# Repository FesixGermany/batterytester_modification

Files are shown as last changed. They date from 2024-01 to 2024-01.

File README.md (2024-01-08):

# batterytester_modification  

Own design to replace the PCB and the support material of a commercially available battery tester.  
The main PCB is made from 1.5mm FR4 material, the support underneath is 2mm FR4.  
The fixed probe PCB was desoldered and reused, the sliding probe assembly was also reused.  
All tested with 30A current, no excessive heat detected with thermal camera.  
  
Changes made compared to original tester:  
- Slots for sliding probe elongated to accept at least a 18650 comfortably and also button cells  
- Wider traces for higher testing current  
- Longer cables for sliding probe  
- Four big holes added to accept 4mm plugs  
  
KiCAD 3D render of PCB:  
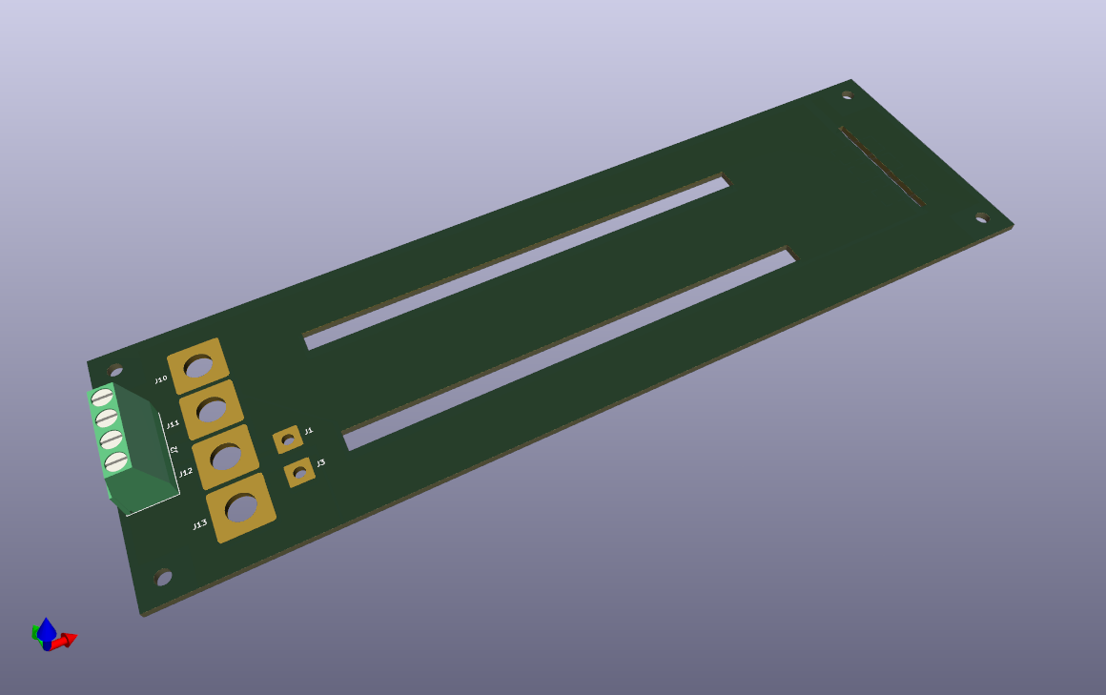
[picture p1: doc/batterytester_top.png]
PCB top
  
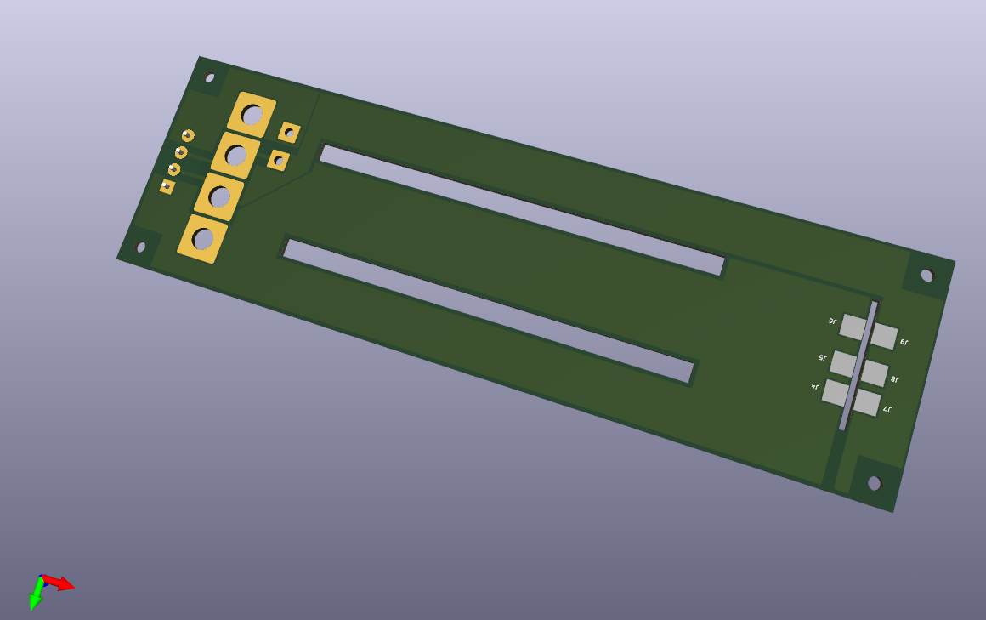
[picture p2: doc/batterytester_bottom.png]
PCB bottom
  
  
Original tester:  
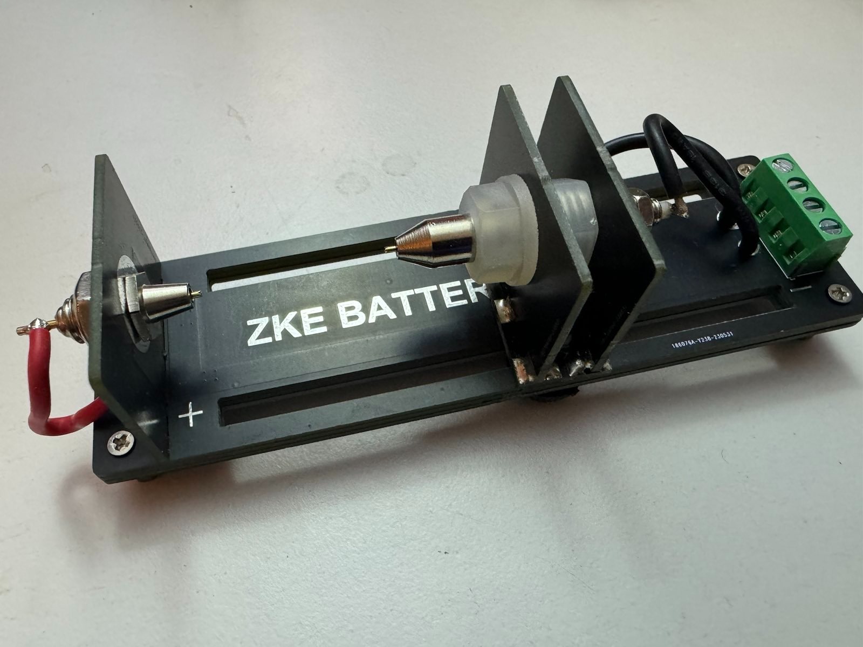
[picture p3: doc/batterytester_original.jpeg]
Original batterytester
  
  
Own version with reused parts:  
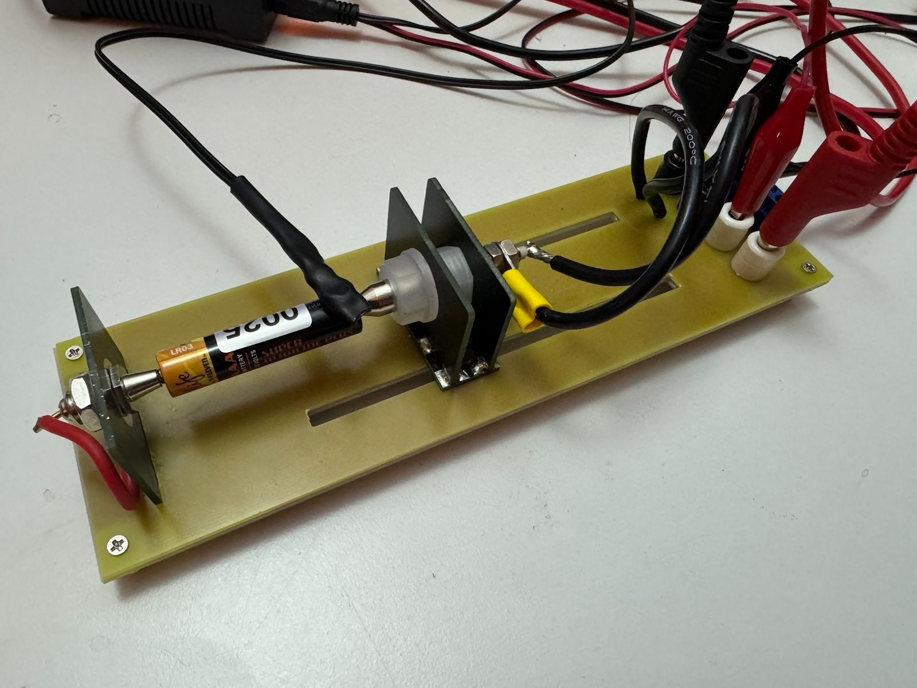
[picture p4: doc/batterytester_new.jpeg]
Tester after modification


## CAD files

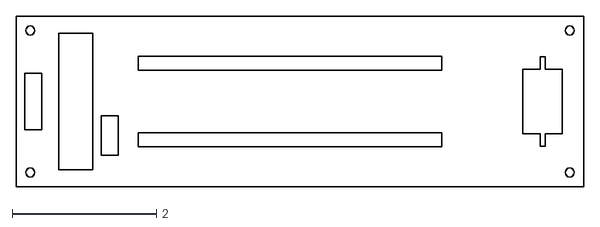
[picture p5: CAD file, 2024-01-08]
gerber_support/batterytester-User_Drawings.dxf
7.87 x 2.36

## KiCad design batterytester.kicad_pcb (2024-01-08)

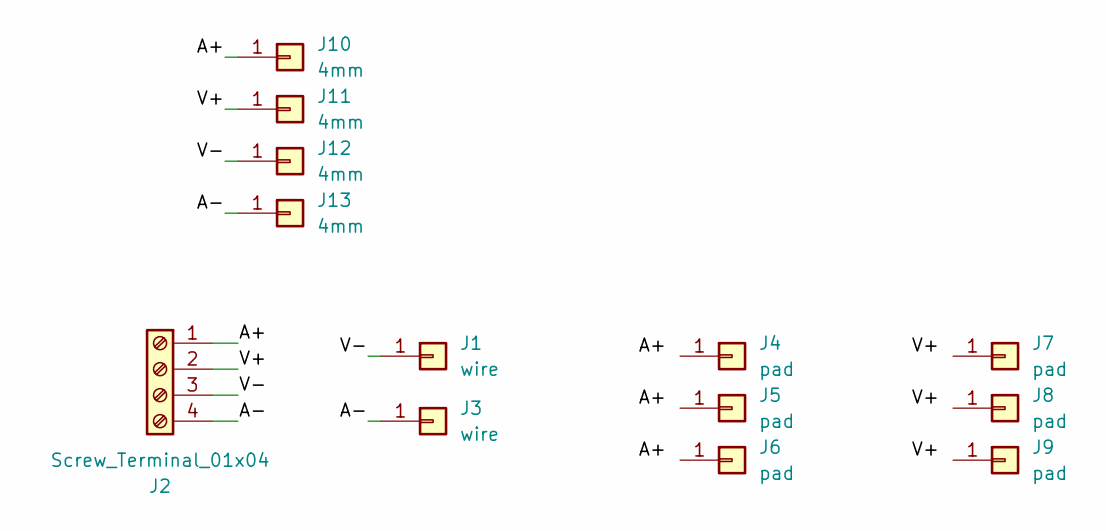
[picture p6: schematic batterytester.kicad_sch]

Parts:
J1, J3: wire; SolderWire-2.5sqmm_1x01_D2.4mm_OD3.6mm
J2: Screw_Terminal_01x04; TerminalBlock_Phoenix_MKDS-1,5-4_1x04_P5.00mm_Horizontal
J4, J5, J6, J7, J8, J9: pad; SolderWirePad_1x01_SMD_5x10mm
J10, J11, J12, J13: 4mm; SolderWire-2sqmm_1x01_D2mm_OD3.9mm

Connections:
/A+: J2.1, J4.1, J5.1, J6.1, J10.1
/A-: J2.4, J3.1, J13.1
/V+: J2.2, J7.1, J8.1, J9.1, J11.1
/V-: J1.1, J2.3, J12.1

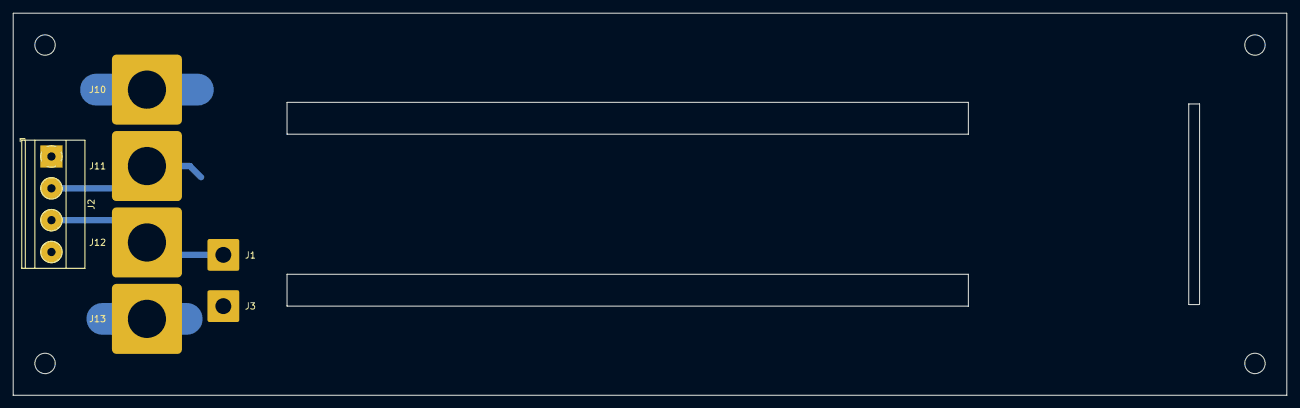
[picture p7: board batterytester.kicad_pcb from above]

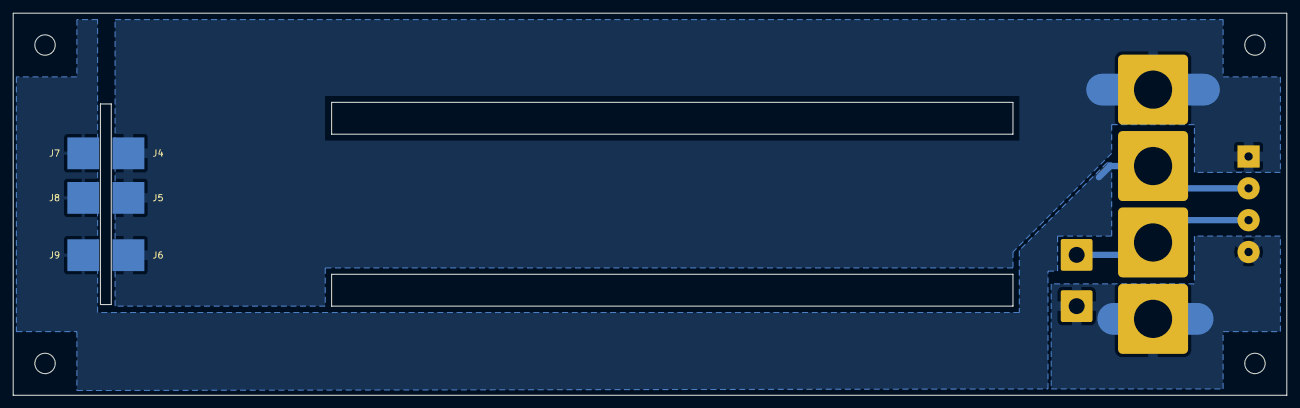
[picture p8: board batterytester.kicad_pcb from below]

Board: 2 copper layers, 200.0 x 60.0 mm, 13 parts (6 on the bottom side), 4 nets.
